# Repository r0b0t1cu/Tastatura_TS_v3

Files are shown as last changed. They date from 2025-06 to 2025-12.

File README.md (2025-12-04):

# Custom Keyboard for Turbo Spectrum

This is an open-source project for a mechanical keyboard compatible with the Romanian Turbo Spectrum computer: https://cobrasov.org/

The keyboard is designed to be easy to build, using accessible and commonly available components.
It also works with the classic ZX Spectrum, offering full compatibility with both systems.

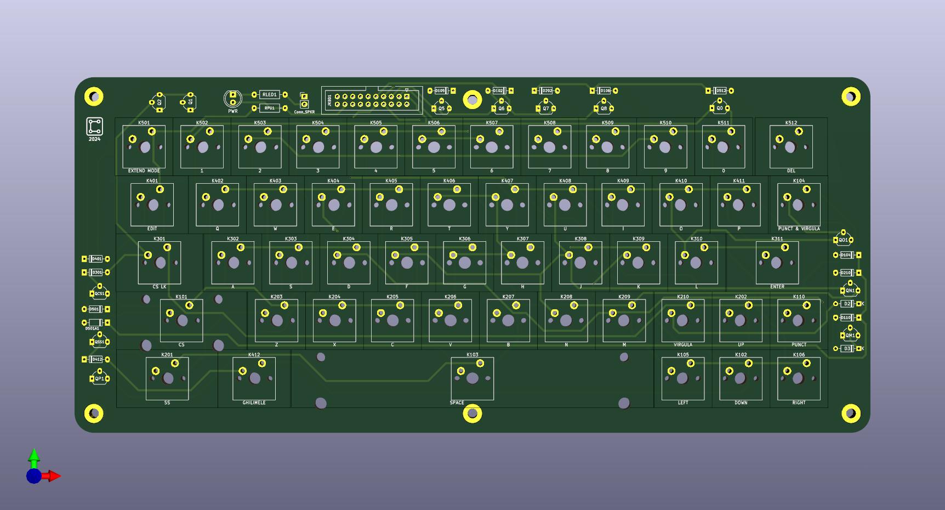
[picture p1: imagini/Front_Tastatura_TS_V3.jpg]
Keyboard PCB


# Keyboard PCB

The Gerber files are located in the production folder.

**Instructions for installing the required key switch libraries:**

Open the KiCad Plugin and Content Manager (PCM) and click Manage. Add a new entry with the plus button and paste the following URL:
https://raw.githubusercontent.com/ebastler/ebastler-KiCad-repository/main/repository.json

From now on, the "ebastler KiCad repository" will appear in your drop-down list, allowing you to easily install and update marbastlib directly through PCM — simple and hassle-free.

# Tastatură Custom pentru Turbo Spectrum

Acesta este un proiect open-source pentru o tastatură mecanică compatibilă cu computerul românesc **Turbo Spectrum**: https://cobrasov.org/
Tastatura a fost proiectată pentru a fi ușor de construit, utilizând componente accesibile.

Keyboard PCB

Instructiuni pentru librariile de butoane folosite:
Open the KiCad "Plugin and Content Manager" (referred to as "PCM" from now on) and click on "Manage". Add a new entry with the plus sign and paste
https://raw.githubusercontent.com/ebastler/ebastler-KiCad-repository/main/repository.json
From this point on you will have "ebastler KiCad repository" in your drop-down selection, and it will allow you to install (and update) marbastlib through PCM - easy and hassle-free.

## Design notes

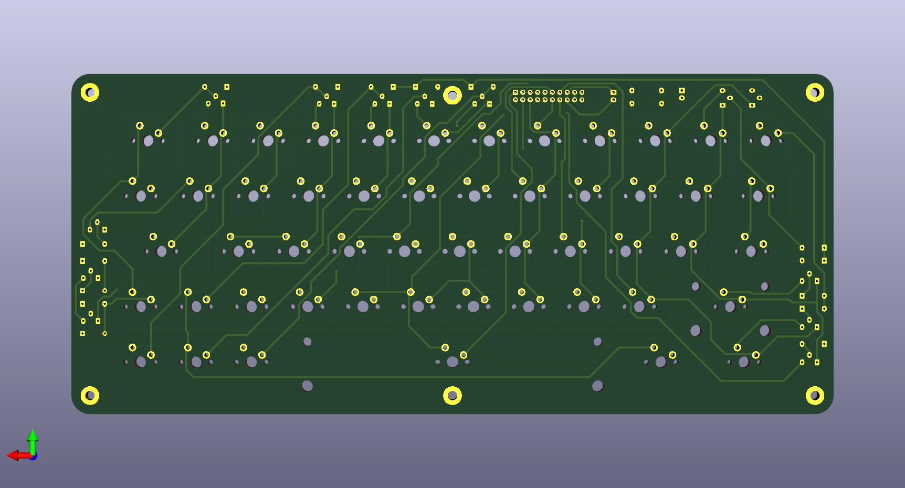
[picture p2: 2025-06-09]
imagini/Back_Tastatura_TS_V3.jpg

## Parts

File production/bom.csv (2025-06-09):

Designator | Footprint | Quantity | Value | LCSC Part #
D1 | LED_D5.0mm | 1 | PWR
D102, D104, D105, D106, D110, D2, D202, D210, D3, D301, D401, D412, D501, D501A1, D512 | D_DO-35_SOD27_P7.62mm_Horizontal | 15 | 1N4148
JKBD1 | IDC-Header_2x10_P2.54mm_Vertical | 1 | Conn_KBD
JSPKR1 | PinHeader_1x02_P2.54mm_Vertical | 1 | Conn_SPKR
K101 | SW_Cherry_MX_2.25u_PCB | 1 | CS
K102 | SW_Cherry_MX_1.00u_PCB | 1 | DOWN
K103 | SW_Cherry_MX_6.25u_PCB | 1 | SPACE
K104 | SW_Cherry_MX_1.00u_PCB | 1 | PUNCT & VIRGULA
K105 | SW_Cherry_MX_1.00u_PCB | 1 | LEFT
K106 | SW_Cherry_MX_1.00u_PCB | 1 | RIGHT
K110 | SW_Cherry_MX_1.00u_PCB | 1 | PUNCT
K201 | SW_Cherry_MX_1.75u_PCB | 1 | SS
K202 | SW_Cherry_MX_1.00u_PCB | 1 | UP
K203 | SW_Cherry_MX_1.00u_PCB | 1 | Z
K204 | SW_Cherry_MX_1.00u_PCB | 1 | X
K205 | SW_Cherry_MX_1.00u_PCB | 1 | C
K206 | SW_Cherry_MX_1.00u_PCB | 1 | V
K207 | SW_Cherry_MX_1.00u_PCB | 1 | B
K208 | SW_Cherry_MX_1.00u_PCB | 1 | N
K209 | SW_Cherry_MX_1.00u_PCB | 1 | M
K210 | SW_Cherry_MX_1.00u_PCB | 1 | VIRGULA
K301 | SW_Cherry_MX_1.50u_PCB | 1 | CS LK
K302 | SW_Cherry_MX_1.00u_PCB | 1 | A
K303 | SW_Cherry_MX_1.00u_PCB | 1 | S
K304 | SW_Cherry_MX_1.00u_PCB | 1 | D
K305 | SW_Cherry_MX_1.00u_PCB | 1 | F
K306 | SW_Cherry_MX_1.00u_PCB | 1 | G
K307 | SW_Cherry_MX_1.00u_PCB | 1 | H
K308 | SW_Cherry_MX_1.00u_PCB | 1 | J
K309 | SW_Cherry_MX_1.00u_PCB | 1 | K
K310 | SW_Cherry_MX_1.00u_PCB | 1 | L
K311 | SW_Cherry_MX_1.75u_PCB | 1 | ENTER
K401 | SW_Cherry_MX_1.25u_PCB | 1 | EDIT
K402 | SW_Cherry_MX_1.00u_PCB | 1 | Q
K403 | SW_Cherry_MX_1.00u_PCB | 1 | W
K404 | SW_Cherry_MX_1.00u_PCB | 1 | E
K405 | SW_Cherry_MX_1.00u_PCB | 1 | R
K406 | SW_Cherry_MX_1.00u_PCB | 1 | T
K407 | SW_Cherry_MX_1.00u_PCB | 1 | Y
K408 | SW_Cherry_MX_1.00u_PCB | 1 | U
K409 | SW_Cherry_MX_1.00u_PCB | 1 | I
K410 | SW_Cherry_MX_1.00u_PCB | 1 | O
K411 | SW_Cherry_MX_1.00u_PCB | 1 | P
K412 | SW_Cherry_MX_1.25u_PCB | 1 | GHILIMELE
K501 | SW_Cherry_MX_1.00u_PCB | 1 | EXTEND MODE
K502 | SW_Cherry_MX_1.00u_PCB | 1 | 1
K503 | SW_Cherry_MX_1.00u_PCB | 1 | 2
K504 | SW_Cherry_MX_1.00u_PCB | 1 | 3
K505 | SW_Cherry_MX_1.00u_PCB | 1 | 4
K506 | SW_Cherry_MX_1.00u_PCB | 1 | 5
K507 | SW_Cherry_MX_1.00u_PCB | 1 | 6
K508 | SW_Cherry_MX_1.00u_PCB | 1 | 7
K509 | SW_Cherry_MX_1.00u_PCB | 1 | 8
K510 | SW_Cherry_MX_1.00u_PCB | 1 | 9
K511 | SW_Cherry_MX_1.00u_PCB | 1 | 0
K512 | SW_Cherry_MX_1.25u_PCB | 1 | DEL
Q0, Q1, Q2, Q5, Q6, Q7, Q8, QCS1, QM1, QN1, QO1, QP1, QSS1 | TO-92_Wide | 13 | BC337
RLED1 | R_Axial_DIN0207_L6.3mm_D2.5mm_P10.16mm_Horizontal | 1 | 1K
RPU1 | R_Axial_DIN0207_L6.3mm_D2.5mm_P10.16mm_Horizontal | 1 | 1.5K

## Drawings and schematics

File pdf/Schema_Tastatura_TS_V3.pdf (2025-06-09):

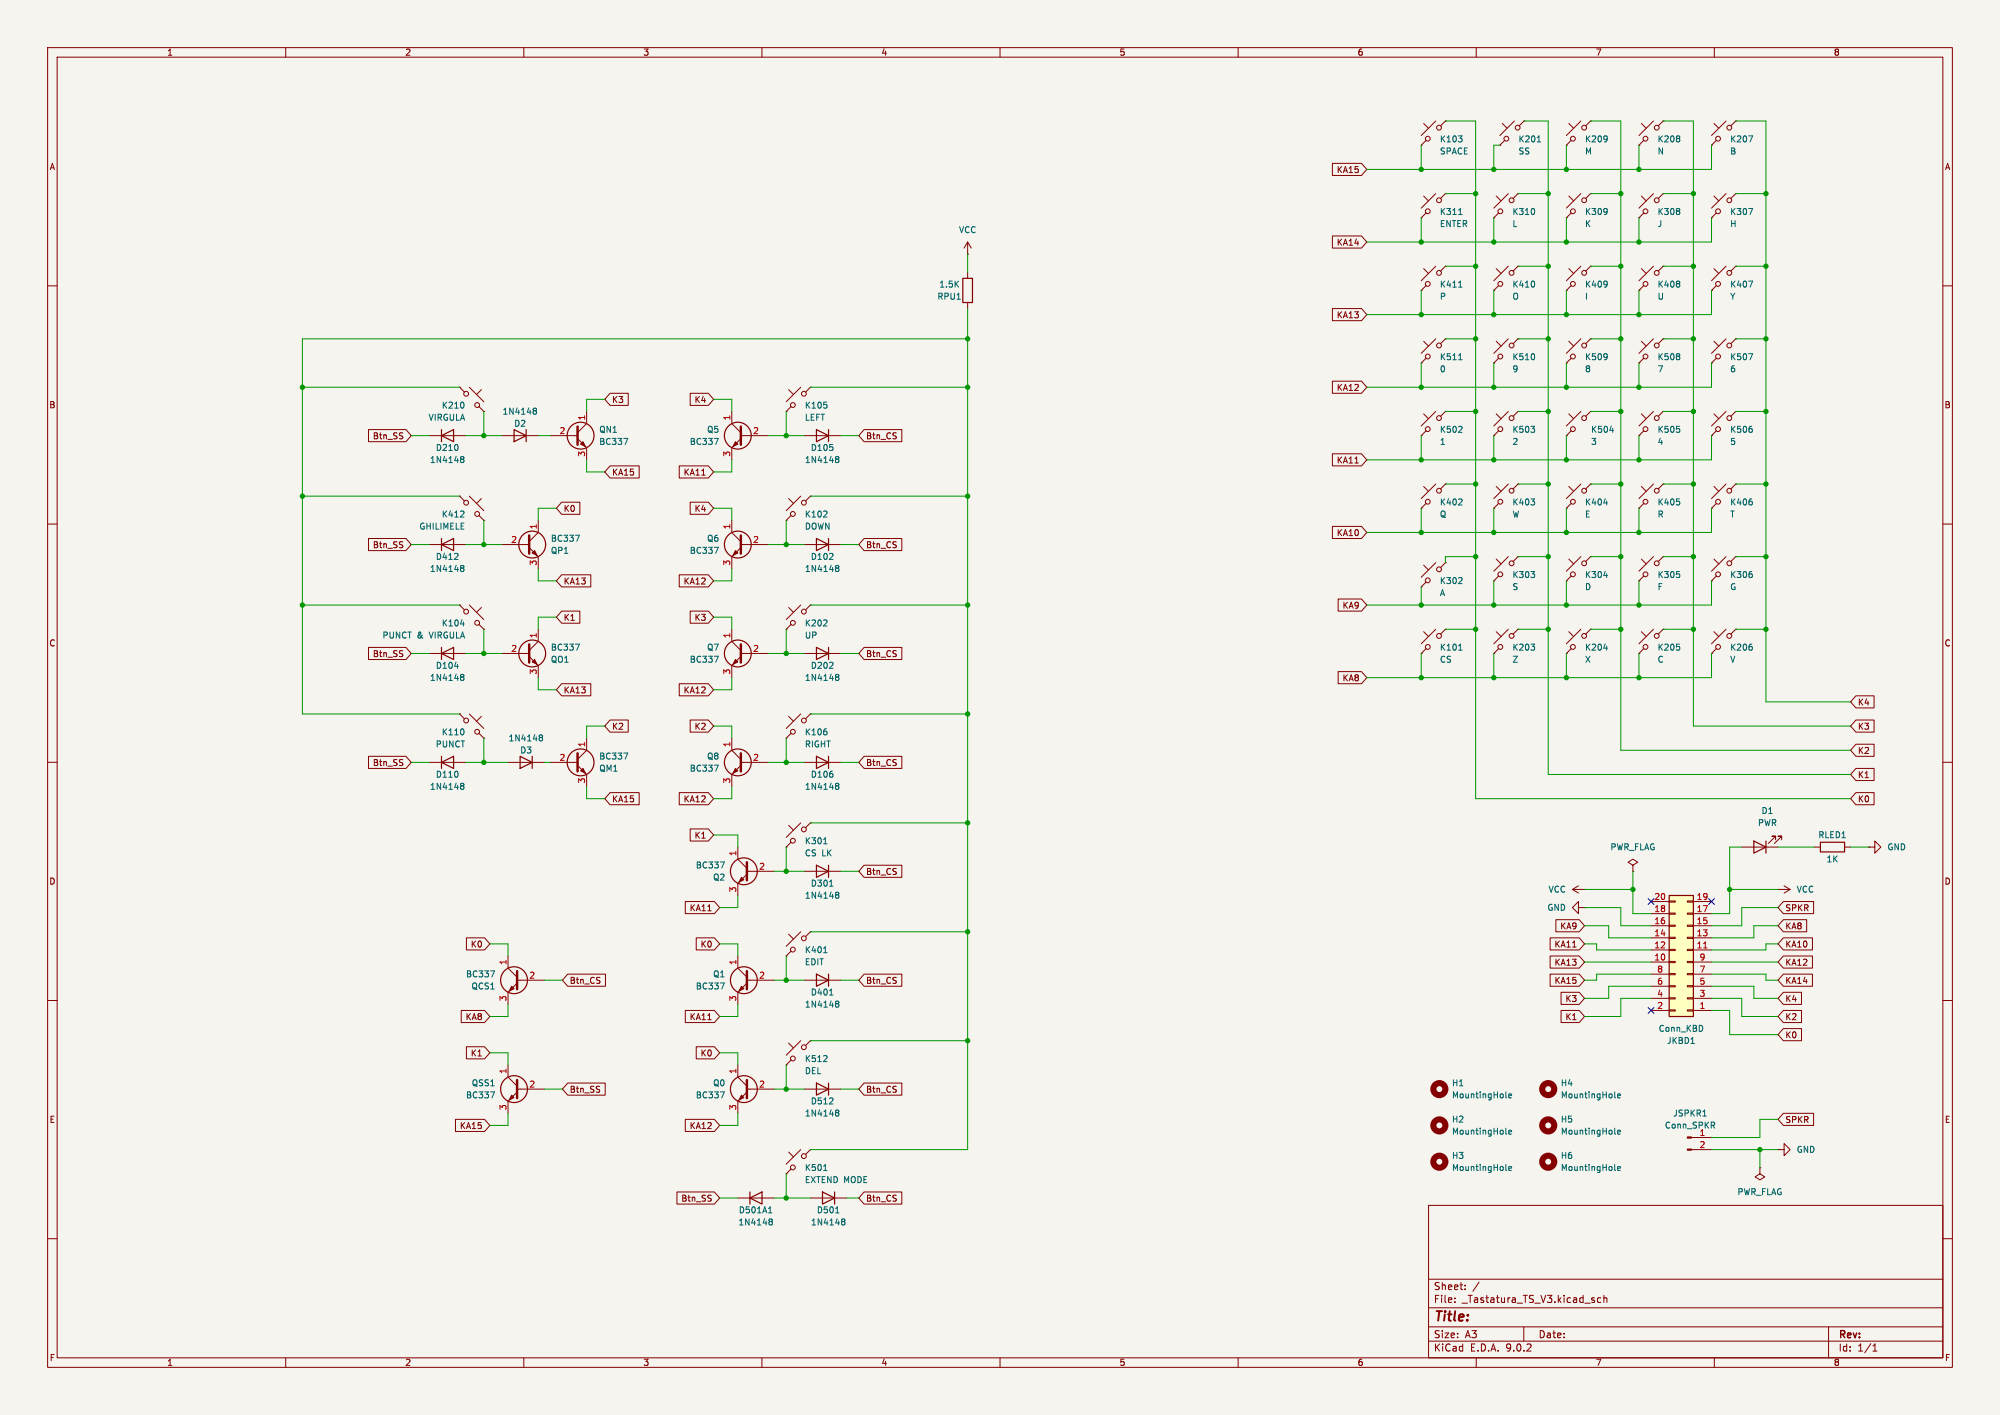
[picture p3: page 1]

Id: 1/1 Title: File: _Tastatura_TS_V3.kicad_sch Sheet: /

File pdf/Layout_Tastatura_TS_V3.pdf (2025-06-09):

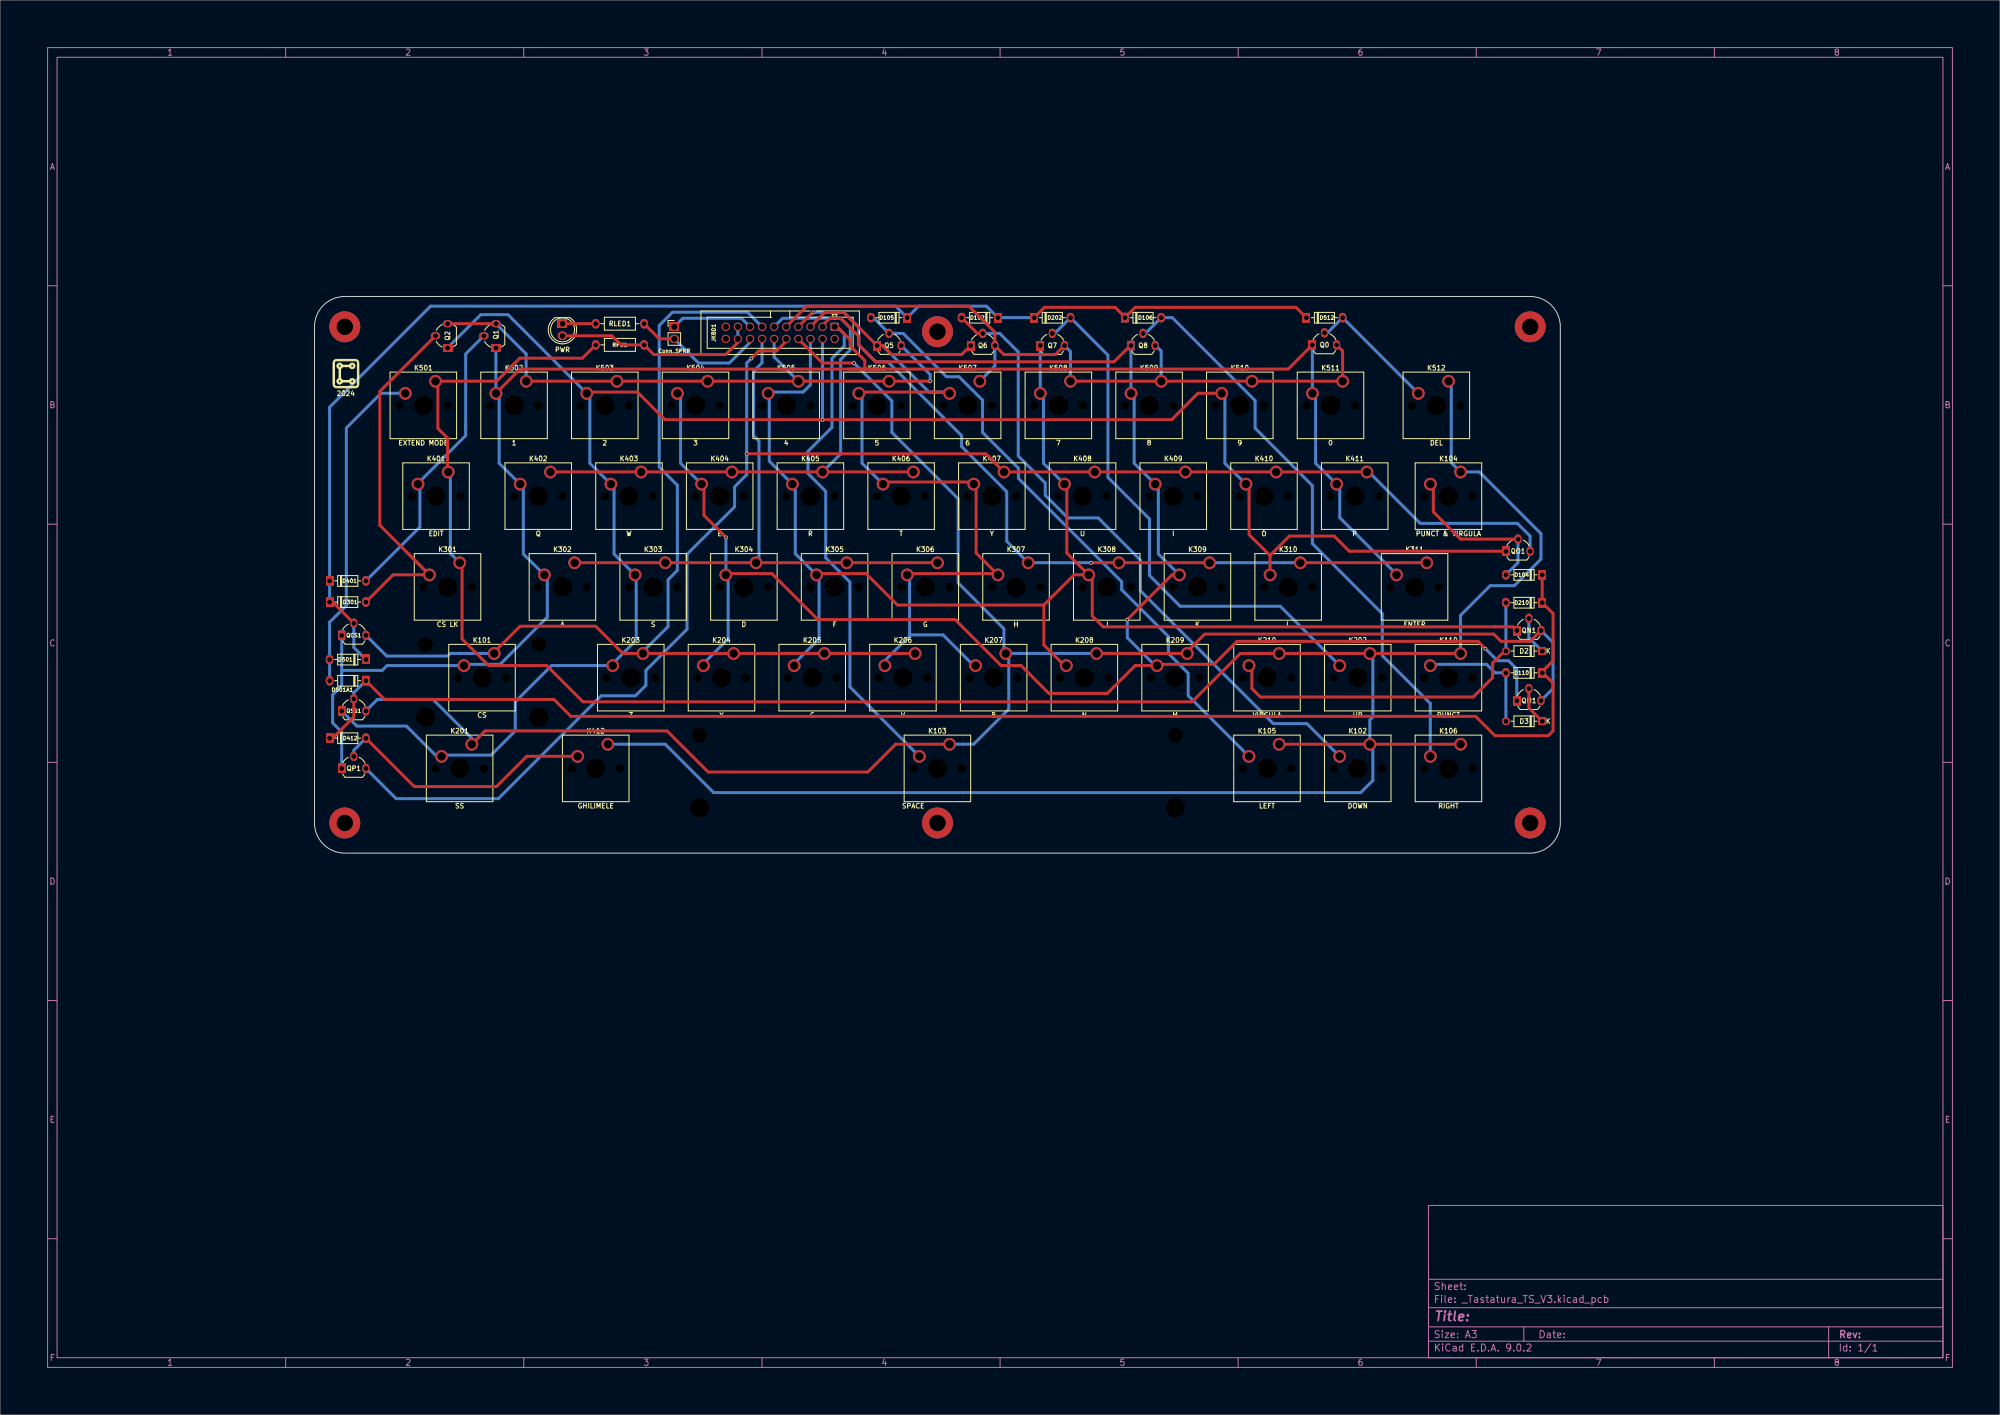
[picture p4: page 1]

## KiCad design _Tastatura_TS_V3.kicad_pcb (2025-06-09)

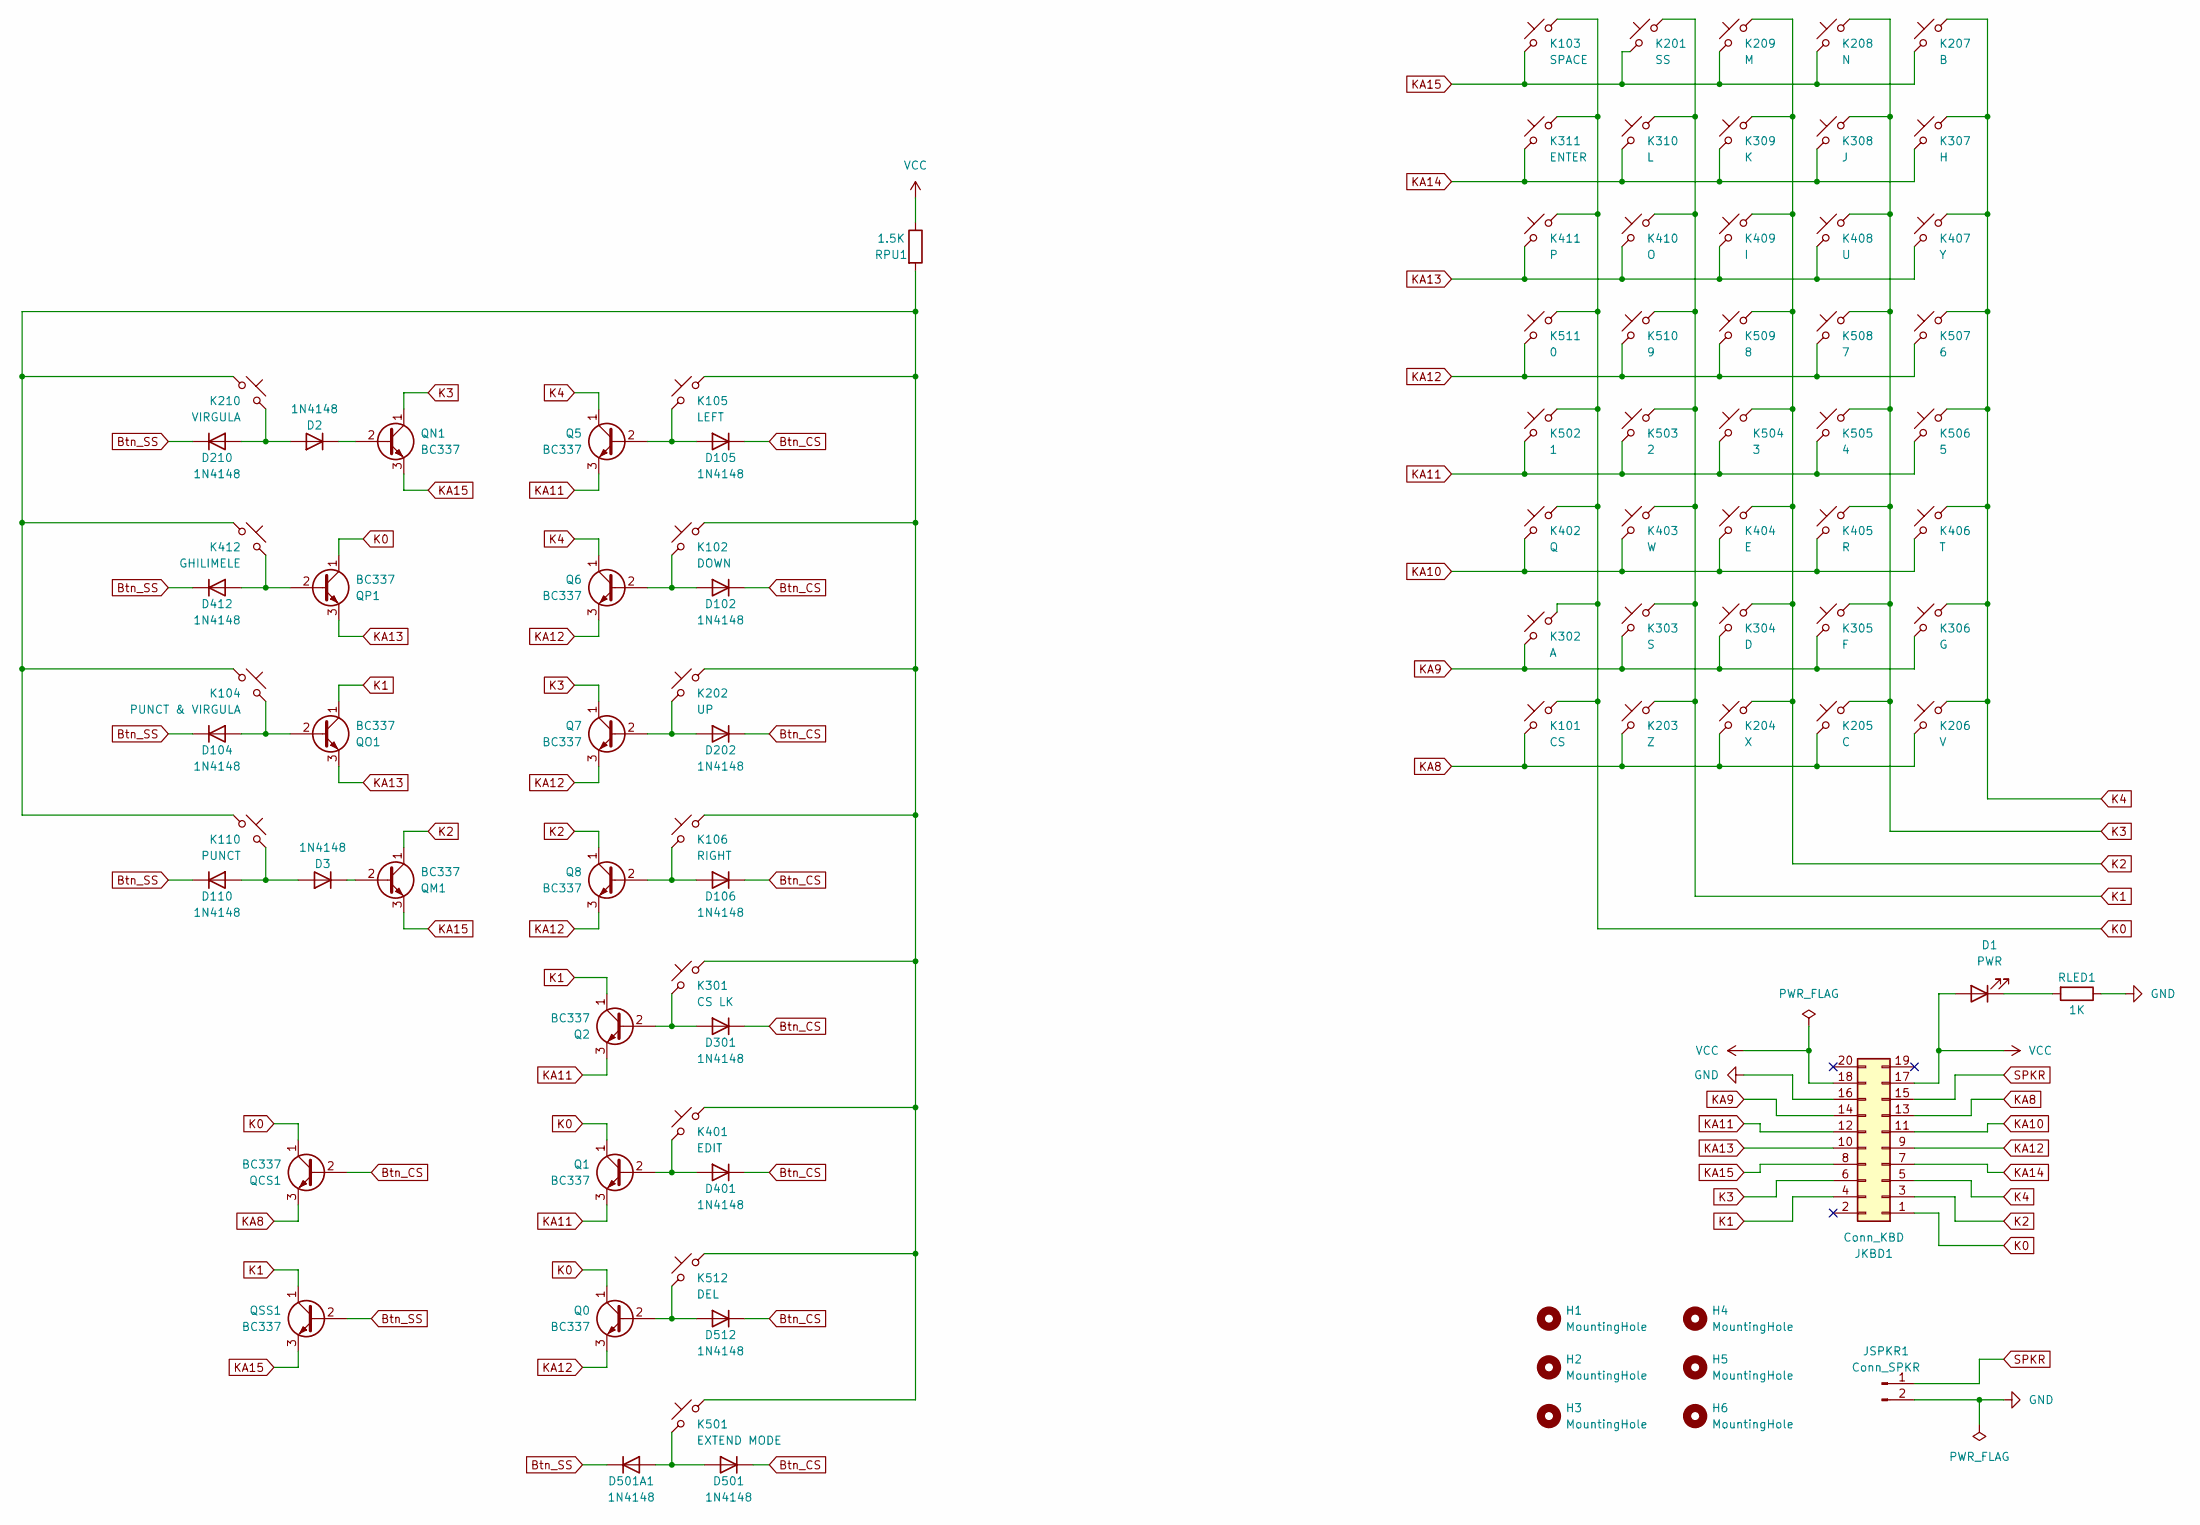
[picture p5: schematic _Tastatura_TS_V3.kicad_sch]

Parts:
D1: PWR; LED_D5.0mm
D2, D3, D102, D104, D105, D106, D110, D202, D210, D301, D401, D412, D501, D501A1, D512: 1N4148; D_DO-35_SOD27_P7.62mm_Horizontal
H1, H2, H3, H4, H5, H6: MountingHole; MountingHole_3.2mm_M3_Pad
JKBD1: Conn_KBD; IDC-Header_2x10_P2.54mm_Vertical
JSPKR1: Conn_SPKR; PinHeader_1x02_P2.54mm_Vertical
K101: CS; SW_Cherry_MX_2.25u_PCB
K102: DOWN; SW_Cherry_MX_1.00u_PCB
K103: SPACE; SW_Cherry_MX_6.25u_PCB
K104: PUNCT & VIRGULA; SW_Cherry_MX_1.00u_PCB
K105: LEFT; SW_Cherry_MX_1.00u_PCB
K106: RIGHT; SW_Cherry_MX_1.00u_PCB
K110: PUNCT; SW_Cherry_MX_1.00u_PCB
K201: SS; SW_Cherry_MX_1.75u_PCB
K202: UP; SW_Cherry_MX_1.00u_PCB
K203: Z; SW_Cherry_MX_1.00u_PCB
K204: X; SW_Cherry_MX_1.00u_PCB
K205: C; SW_Cherry_MX_1.00u_PCB
K206: V; SW_Cherry_MX_1.00u_PCB
K207: B; SW_Cherry_MX_1.00u_PCB
K208: N; SW_Cherry_MX_1.00u_PCB
K209: M; SW_Cherry_MX_1.00u_PCB
K210: VIRGULA; SW_Cherry_MX_1.00u_PCB
K301: CS LK; SW_Cherry_MX_1.50u_PCB
K302: A; SW_Cherry_MX_1.00u_PCB
K303: S; SW_Cherry_MX_1.00u_PCB
K304: D; SW_Cherry_MX_1.00u_PCB
K305: F; SW_Cherry_MX_1.00u_PCB
K306: G; SW_Cherry_MX_1.00u_PCB
K307: H; SW_Cherry_MX_1.00u_PCB
K308: J; SW_Cherry_MX_1.00u_PCB
K309: K; SW_Cherry_MX_1.00u_PCB
K310: L; SW_Cherry_MX_1.00u_PCB
K311: ENTER; SW_Cherry_MX_1.75u_PCB
K401: EDIT; SW_Cherry_MX_1.25u_PCB
K402: Q; SW_Cherry_MX_1.00u_PCB
K403: W; SW_Cherry_MX_1.00u_PCB
K404: E; SW_Cherry_MX_1.00u_PCB
K405: R; SW_Cherry_MX_1.00u_PCB
K406: T; SW_Cherry_MX_1.00u_PCB
K407: Y; SW_Cherry_MX_1.00u_PCB
K408: U; SW_Cherry_MX_1.00u_PCB
K409: I; SW_Cherry_MX_1.00u_PCB
K410: O; SW_Cherry_MX_1.00u_PCB
K411: P; SW_Cherry_MX_1.00u_PCB
K412: GHILIMELE; SW_Cherry_MX_1.25u_PCB
K501: EXTEND MODE; SW_Cherry_MX_1.00u_PCB
K502: 1; SW_Cherry_MX_1.00u_PCB
K503: 2; SW_Cherry_MX_1.00u_PCB
K504: 3; SW_Cherry_MX_1.00u_PCB
K505: 4; SW_Cherry_MX_1.00u_PCB
K506: 5; SW_Cherry_MX_1.00u_PCB
K507: 6; SW_Cherry_MX_1.00u_PCB
K508: 7; SW_Cherry_MX_1.00u_PCB
K509: 8; SW_Cherry_MX_1.00u_PCB
K510: 9; SW_Cherry_MX_1.00u_PCB
K511: 0; SW_Cherry_MX_1.00u_PCB
K512: DEL; SW_Cherry_MX_1.25u_PCB
Q0, Q1, Q2, Q5, Q6, Q7, Q8: BC337; TO-92_Wide
QCS1: BC337; TO-92_Wide
QM1: BC337; TO-92_Wide
QN1: BC337; TO-92_Wide
QO1: BC337; TO-92_Wide
QP1: BC337; TO-92_Wide
QSS1: BC337; TO-92_Wide
RLED1: 1K; R_Axial_DIN0207_L6.3mm_D2.5mm_P10.16mm_Horizontal
RPU1: 1.5K; R_Axial_DIN0207_L6.3mm_D2.5mm_P10.16mm_Horizontal

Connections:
Btn_CS: D102.1 (K), D105.1 (K), D106.1 (K), D202.1 (K), D301.1 (K), D401.1 (K), D501.1 (K), D512.1 (K), QCS1.2 (B)
Btn_SS: D104.1 (K), D110.1 (K), D210.1 (K), D412.1 (K), D501A1.1 (K), QSS1.2 (B)
GND: JKBD1.16, JSPKR1.2, RLED1.1
K0: JKBD1.1, K101.2, K103.2, K302.2, K311.2, K402.2, K411.2, K502.2, K511.2, Q0.1 (C), Q1.1 (C), QCS1.1 (C), QP1.1 (C)
K1: JKBD1.4, K201.2, K203.2, K303.2, K310.2, K403.2, K410.2, K503.2, K510.2, Q2.1 (C), QO1.1 (C), QSS1.1 (C)
K2: JKBD1.3, K204.2, K209.2, K304.2, K309.2, K404.2, K409.2, K504.2, K509.2, Q8.1 (C), QM1.1 (C)
K3: JKBD1.6, K205.2, K208.2, K305.2, K308.2, K405.2, K408.2, K505.2, K508.2, Q7.1 (C), QN1.1 (C)
K4: JKBD1.5, K206.2, K207.2, K306.2, K307.2, K406.2, K407.2, K506.2, K507.2, Q5.1 (C), Q6.1 (C)
KA8: JKBD1.13, K101.1, K203.1, K204.1, K205.1, K206.1, QCS1.3 (E)
KA9: JKBD1.14, K302.1, K303.1, K304.1, K305.1, K306.1
KA10: JKBD1.11, K402.1, K403.1, K404.1, K405.1, K406.1
KA11: JKBD1.12, K502.1, K503.1, K504.1, K505.1, K506.1, Q1.3 (E), Q2.3 (E), Q5.3 (E)
KA12: JKBD1.9, K507.1, K508.1, K509.1, K510.1, K511.1, Q0.3 (E), Q6.3 (E), Q7.3 (E), Q8.3 (E)
KA13: JKBD1.10, K407.1, K408.1, K409.1, K410.1, K411.1, QO1.3 (E), QP1.3 (E)
KA14: JKBD1.7, K307.1, K308.1, K309.1, K310.1, K311.1
KA15: JKBD1.8, K103.1, K201.1, K207.1, K208.1, K209.1, QM1.3 (E), QN1.3 (E), QSS1.3 (E)
unnamed: D1.1 (K), RLED1.2
unnamed: D2.2 (A), D210.2 (A), K210.2
unnamed: D2.1 (K), QN1.2 (B)
unnamed: D3.1 (K), QM1.2 (B)
unnamed: D102.2 (A), K102.2, Q6.2 (B)
unnamed: D104.2 (A), K104.2, QO1.2 (B)
unnamed: D105.2 (A), K105.2, Q5.2 (B)
unnamed: D106.2 (A), K106.2, Q8.2 (B)
unnamed: D3.2 (A), D110.2 (A), K110.2
unnamed: D202.2 (A), K202.2, Q7.2 (B)
unnamed: D301.2 (A), K301.2, Q2.2 (B)
unnamed: D401.2 (A), K401.2, Q1.2 (B)
unnamed: D412.2 (A), K412.2, QP1.2 (B)
unnamed: D501.2 (A), D501A1.2 (A), K501.2
unnamed: D512.2 (A), K512.2, Q0.2 (B)
unnamed: K102.1, K104.1, K105.1, K106.1, K110.1, K202.1, K210.1, K301.1, K401.1, K412.1, K501.1, K512.1, RPU1.2
SPKR: JKBD1.15, JSPKR1.1
VCC: D1.2 (A), JKBD1.17, JKBD1.18, RPU1.1

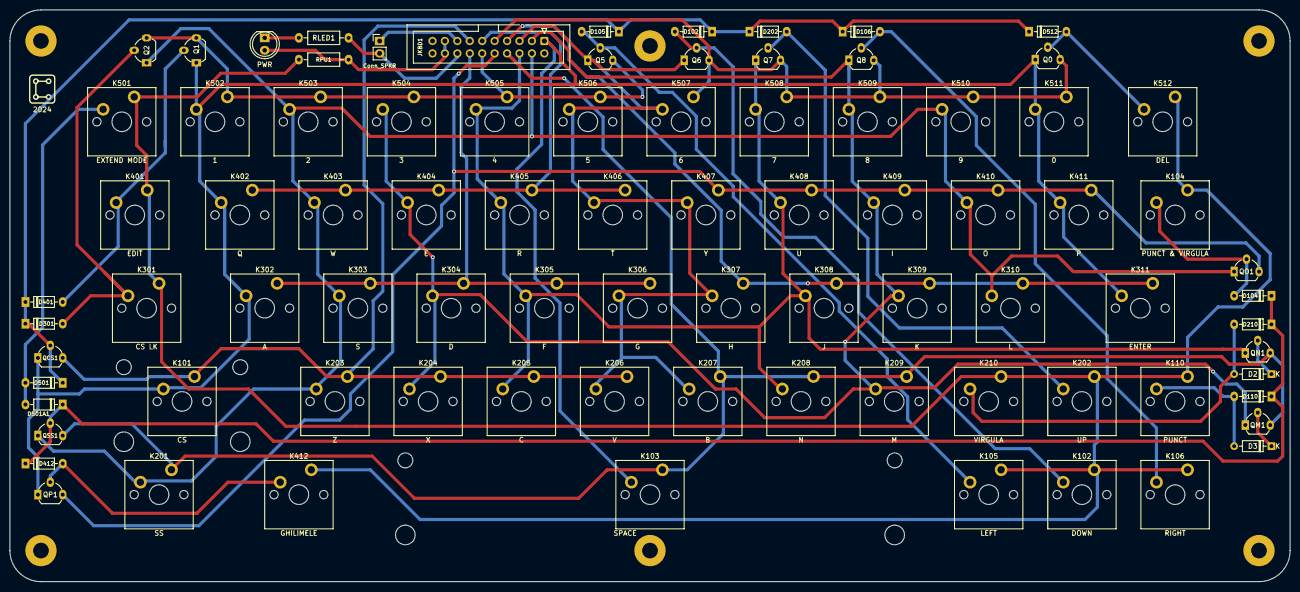
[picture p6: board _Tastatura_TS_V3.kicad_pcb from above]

Board: 2 copper layers, 261.6 x 116.8 mm, 91 parts (0 on the bottom side), 34 nets.
